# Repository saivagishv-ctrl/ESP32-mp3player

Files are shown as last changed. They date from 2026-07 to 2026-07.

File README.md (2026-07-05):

This is my first ever pcb project, I used AI to ask questions about the KiCAD ui, and to recommend me a specifec model number when i gave it constraints for what i wanted in a component, like the charging module for the battery with passthrough and voltage detection
breakdown of cost: jlcpcb manufacturing total:35 dollar (so much shipping cost and no way to cancel it, not even with other companies)
parts cost on jlcpcb: 25ish dollars without shipping

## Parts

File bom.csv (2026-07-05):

Designator | Footprint | Quantity | Value | LCSC Part #
BT1 | JST_PH_S2B-PH-K_1x02_P2.00mm_Horizontal | 1 | batt
C1, C13, C15, C2, C5 | 0805 | 5 | 10 uF
C10, C11 | 0805 | 2 | 2.2 nF
C12, C14 | 0805 | 2 | 0.1 uF
C16, C17, C6 | 0805 | 3 | 100 nF
C3 | 0805 | 1 | 1uF
C4 | 0805 | 1 | 47 uf
C7, C8 | 0805 | 2 | 2.2 uF
C9 | 0805 | 1 | 1 uF
J1 | USB_C_Receptacle_GCT_USB4105-xx-A_16P_TopMnt_Horizontal | 1 | USB_C_Receptacle_USB2.0_16P
J16 | PinHeader_1x14_P2.54mm_Vertical | 1 | PINHD_1x14_Male
J2 | Jack_3.5mm_CUI_SJ1-3533NG_Horizontal | 1 | AudioJack3
J3 | microSD_HC_Molex_104031-0811 | 1 | Micro_SD_Card_Det1
R1 | R_Axial_DIN0207_L6.3mm_D2.5mm_P10.16mm_Horizontal | 1 | 2k
R10, R11, R12, R13, R14, R15, R16, R17, R2, R3, R4, R9 | R_Axial_DIN0207_L6.3mm_D2.5mm_P10.16mm_Horizontal | 12 | 10k
R5, R8 | R_Axial_DIN0207_L6.3mm_D2.5mm_P10.16mm_Horizontal | 2 | 470ohm
R6, R7 | R_Axial_DIN0207_L6.3mm_D2.5mm_P10.16mm_Horizontal | 2 | 5.1k
SW1, SW2 | SW_Push_SPST_NO_Alps_SKRK | 2 | SW_SPST
U1 | QFN-20-1EP_4x4mm_P0.5mm_EP2.5x2.5mm | 1 | MCP73871-2CC
U2 | ESP32-S3-WROOM-1 | 1 | ESP32-S3-WROOM-1
U3 | SOT-223-3_TabPin2 | 1 | LT1963AxST-3.3
U4 | TSSOP-20_4.4x6.5mm_P0.65mm | 1 | PCM5102A

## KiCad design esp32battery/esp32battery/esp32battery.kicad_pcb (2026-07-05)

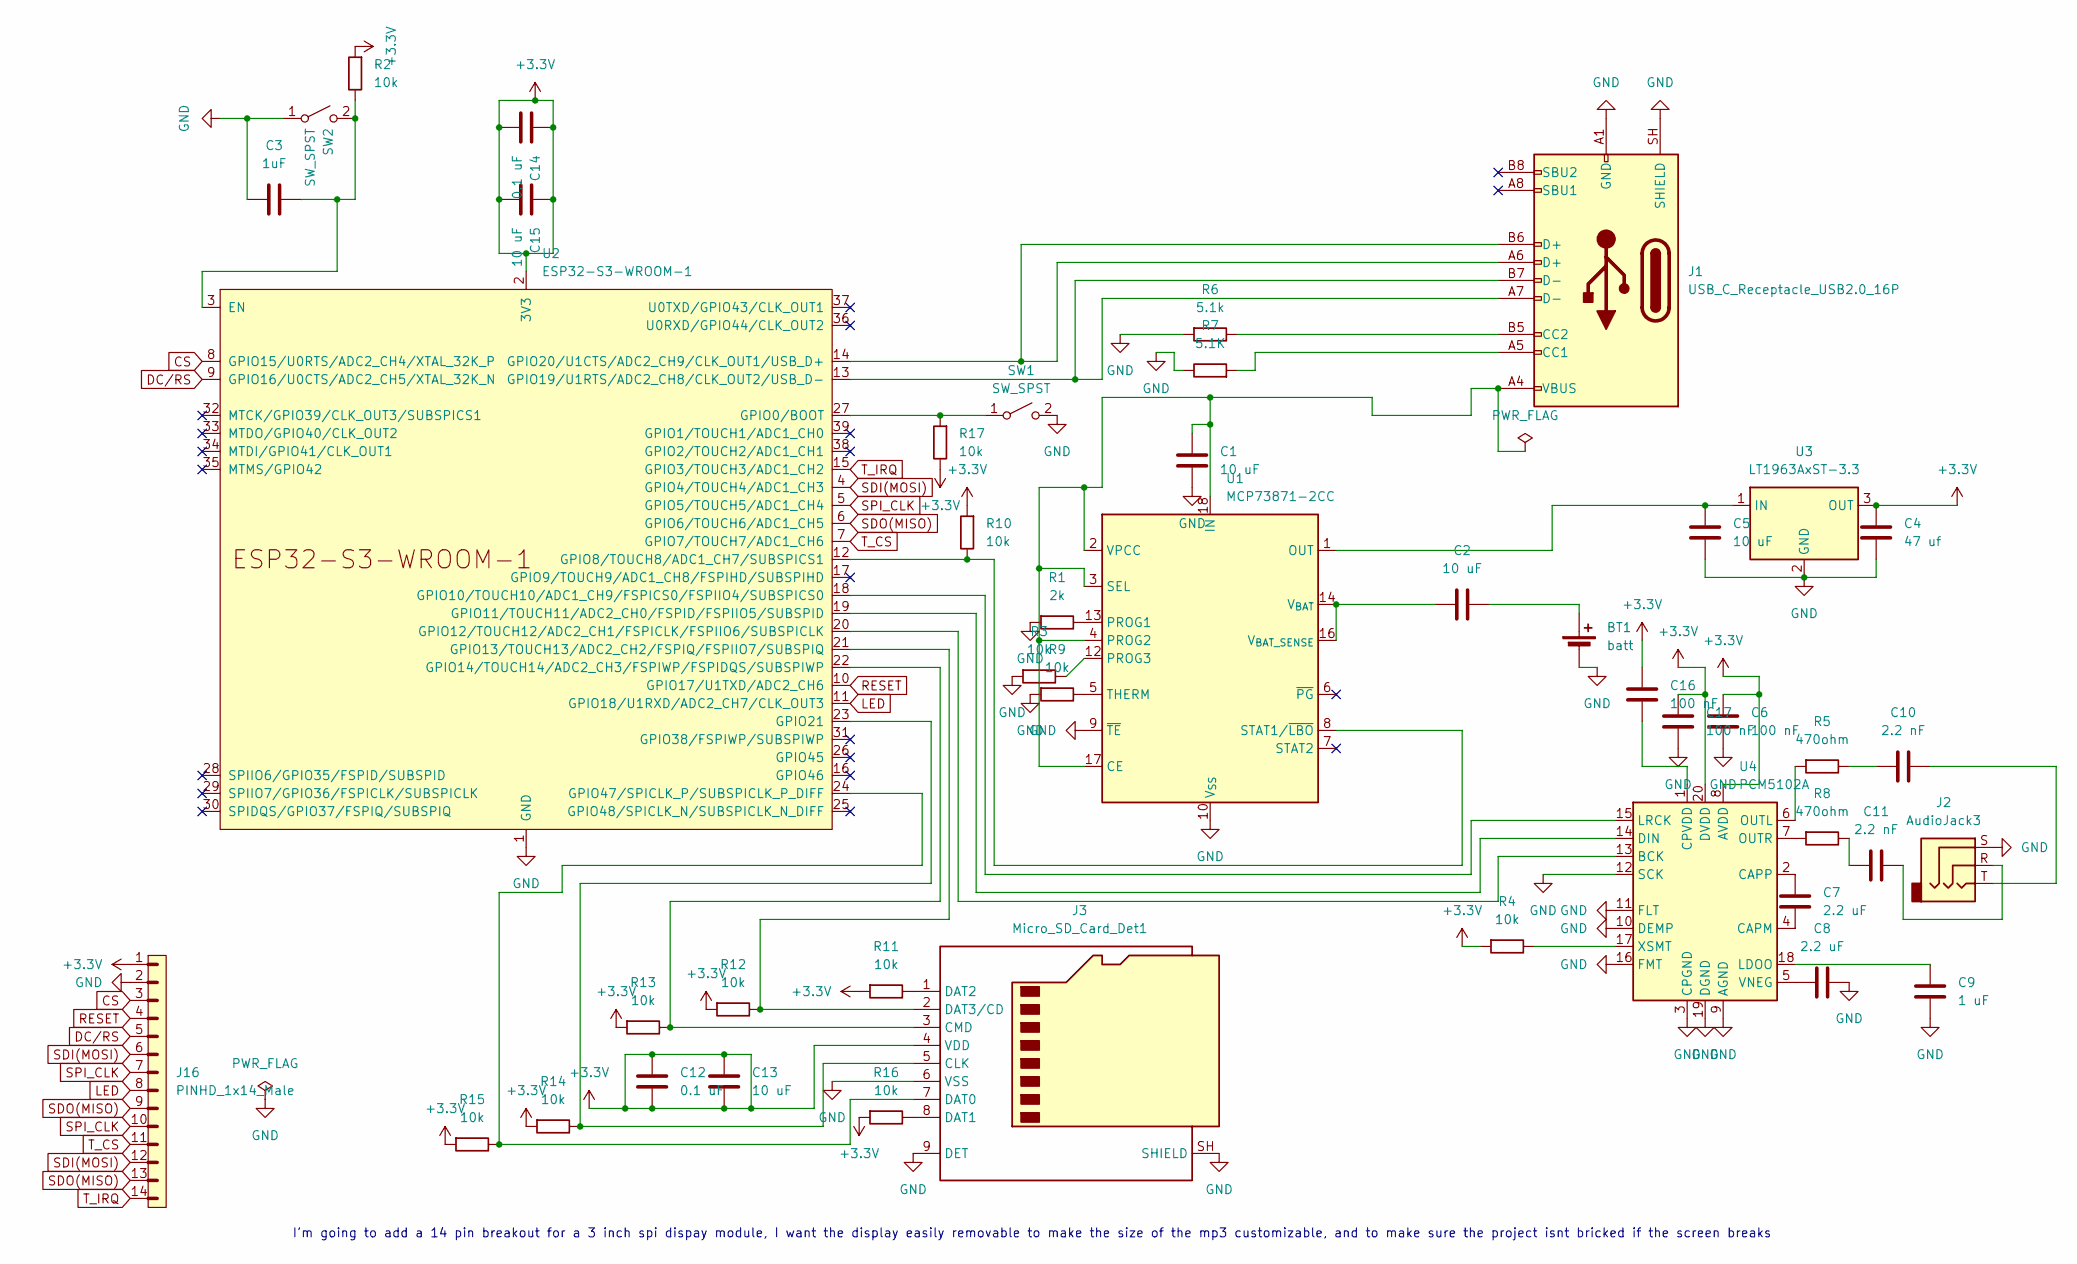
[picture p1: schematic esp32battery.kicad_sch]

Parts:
BT1: batt; JST_PH_S2B-PH-K_1x02_P2.00mm_Horizontal
C1, C2, C5, C13, C15: 10 uF; C_0805_2012Metric_Pad1.18x1.45mm_HandSolder
C3: 1uF; C_0805_2012Metric_Pad1.18x1.45mm_HandSolder
C4: 47 uf; C_0805_2012Metric_Pad1.18x1.45mm_HandSolder
C6, C16, C17: 100 nF; C_0805_2012Metric_Pad1.18x1.45mm_HandSolder
C7, C8: 2.2 uF; C_0805_2012Metric_Pad1.18x1.45mm_HandSolder
C9: 1 uF; C_0805_2012Metric_Pad1.18x1.45mm_HandSolder
C10, C11: 2.2 nF; C_0805_2012Metric_Pad1.18x1.45mm_HandSolder
C12, C14: 0.1 uF; C_0805_2012Metric_Pad1.18x1.45mm_HandSolder
J1: USB_C_Receptacle_USB2.0_16P; USB_C_Receptacle_GCT_USB4105-xx-A_16P_TopMnt_Horizontal
J2: AudioJack3; Jack_3.5mm_CUI_SJ1-3533NG_Horizontal
J3: Micro_SD_Card_Det1; microSD_HC_Molex_104031-0811
J16: PINHD_1x14_Male; PinHeader_1x14_P2.54mm_Vertical
R1: 2k; R_Axial_DIN0207_L6.3mm_D2.5mm_P10.16mm_Horizontal
R2, R3, R4, R9, R10, R11, R12, R13, R14, R15, R16, R17: 10k; R_Axial_DIN0207_L6.3mm_D2.5mm_P10.16mm_Horizontal
R5, R8: 470ohm; R_Axial_DIN0207_L6.3mm_D2.5mm_P10.16mm_Horizontal
R6: 5.1k; R_Axial_DIN0207_L6.3mm_D2.5mm_P10.16mm_Horizontal
R7: 5.1K; R_Axial_DIN0207_L6.3mm_D2.5mm_P10.16mm_Horizontal
SW1, SW2: SW_SPST; SW_Push_SPST_NO_Alps_SKRK
U1: MCP73871-2CC; QFN-20-1EP_4x4mm_P0.5mm_EP2.5x2.5mm
U2: ESP32-S3-WROOM-1
U3: LT1963AxST-3.3; SOT-223-3_TabPin2
U4: PCM5102A; TSSOP-20_4.4x6.5mm_P0.65mm

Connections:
+3.3V: C4.1, C6.1, C12.1, C12.2, C13.1, C13.2, C14.1, C14.2, C15.1, C15.2, C16.1, C17.1, J3.4 (VDD), J16.1, R2.1, R4.1, R10.1, R11.1, R12.1, R13.1, R14.1, R15.1, R16.1, R17.2, U2.2 (3V3), U3.3 (OUT), U4.8 (AVDD), U4.20 (DVDD)
CS: J16.3, U2.8 (GPIO15/U0RTS/ADC2_CH4/XTAL_32K_P)
DC/RS: J16.5, U2.9 (GPIO16/U0CTS/ADC2_CH5/XTAL_32K_N)
GND: BT1.2 (-), C1.2, C3.2, C4.2, C5.2, C6.2, C8.1, C9.2, C17.2, J1.A1 (GND), J1.A12 (GND), J1.B1 (GND), J1.B12 (GND), J1.SH (SHIELD), J2.S, J3.6 (VSS), J3.9 (DET), J3.SH (SHIELD), J16.2, R1.1, R3.1, R6.1, R7.2, R9.1, SW1.2 (B), SW2.1 (A), U1.9 (~TE), U1.10 (V_{SS}), U1.11 (V_{SS}), U1.21 (V_{SS}), U2.1 (GND), U2.40 (GND), U2.41 (GND), U3.2 (GND), U4.3 (CPGND), U4.9 (AGND), U4.10 (DEMP), U4.11 (FLT), U4.12 (SCK), U4.16 (FMT), U4.19 (DGND)
LED: J16.8, U2.11 (GPIO18/U1RXD/ADC2_CH7/CLK_OUT3)
unnamed: BT1.1 (+), C2.1
unnamed: C10.1, J2.T
unnamed: C10.2, R5.2
unnamed: C11.1, R8.2
unnamed: C11.2, J2.R
unnamed: J1.A5 (CC1), R7.1
unnamed: J1.B5 (CC2), R6.2
unnamed: J3.5 (CLK), R14.2, U2.23 (GPIO21)
unnamed: J3.3 (CMD), R13.2, U2.22 (GPIO14/TOUCH14/ADC2_CH3/FSPIWP/FSPIDQS/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)
unnamed: J3.7 (DAT0), R15.2, U2.24 (GPIO47/SPICLK_P/SUBSPICLK_P_DIFF)
unnamed: J3.8 (DAT1), R16.2
unnamed: J3.1 (DAT2), R11.2
unnamed: J3.2 (DAT3/CD), R12.2, U2.21 (GPIO13/TOUCH13/ADC2_CH2/FSPIQ/FSPIIO7/S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)
unnamed: R17.1, SW1.1 (A), U2.27 (GPIO0/BOOT)
unnamed: C3.1, R2.2, SW2.2 (B), U2.3 (EN)
unnamed: C1.1, J1.A4 (VBUS), J1.A9 (VBUS), J1.B4 (VBUS), J1.B9 (VBUS), U1.2 (VPCC), U1.3 (SEL), U1.4 (PROG2), U1.17 (CE), U1.18 (IN), U1.19 (IN)
unnamed: R1.2, U1.13 (PROG1)
unnamed: R3.2, U1.12 (PROG3)
unnamed: R10.2, U1.8 (STAT1/~LBO), U2.12 (GPIO8/TOUCH8/ADC1_CH7/SUBSPICS1)
unnamed: R9.2, U1.5 (THERM)
unnamed: C2.2, U1.14 (V_{BAT}), U1.15 (V_{BAT}), U1.16 (V_{BAT_SENSE})
unnamed: U2.18 (GPIO10/TOUCH10/ADC1_CH9/FSPICS0/FSPIIO4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), U4.15 (LRCK)
unnamed: U2.19 (GPIO11/TOUCH11/ADC2_CH0/FSPID/FSPIIO5/S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), U4.14 (DIN)
unnamed: U2.20 (GPIO12/TOUCH12/ADC2_CH1/FSPICLK/FSPIIO6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), U4.13 (BCK)
unnamed: J1.A7 (D-), J1.B7 (D-), U2.13 (GPIO19/U1RTS/ADC2_CH8/CLK_OUT2/USB_D-)
unnamed: J1.A6 (D+), J1.B6 (D+), U2.14 (GPIO20/U1CTS/ADC2_CH9/CLK_OUT1/USB_D+)
unnamed: C5.1, U1.1 (OUT), U1.20 (OUT), U3.1 (IN)
unnamed: C7.2, U4.4 (CAPM)
unnamed: C7.1, U4.2 (CAPP)
unnamed: C16.2, U4.1 (CPVDD)
unnamed: C9.1, U4.18 (LDOO)
unnamed: R5.1, U4.6 (OUTL)
unnamed: R8.1, U4.7 (OUTR)
unnamed: C8.2, U4.5 (VNEG)
unnamed: R4.2, U4.17 (XSMT)
RESET: J16.4, U2.10 (GPIO17/U1TXD/ADC2_CH6)
SDI(MOSI): J16.6, J16.12, U2.4 (GPIO4/TOUCH4/ADC1_CH3)
SDO(MISO): J16.9, J16.13, U2.6 (GPIO6/TOUCH6/ADC1_CH5)
SPI_CLK: J16.7, J16.10, U2.5 (GPIO5/TOUCH5/ADC1_CH4)
T_CS: J16.11, U2.7 (GPIO7/TOUCH7/ADC1_CH6)
T_IRQ: J16.14, U2.15 (GPIO3/TOUCH3/ADC1_CH2)

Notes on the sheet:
I'm going to add a 14 pin breakout for a 3 inch spi dispay module, I want the display easily removable to make the size of the mp3 customizable, and to make sure the project isnt bricked if the screen breaks

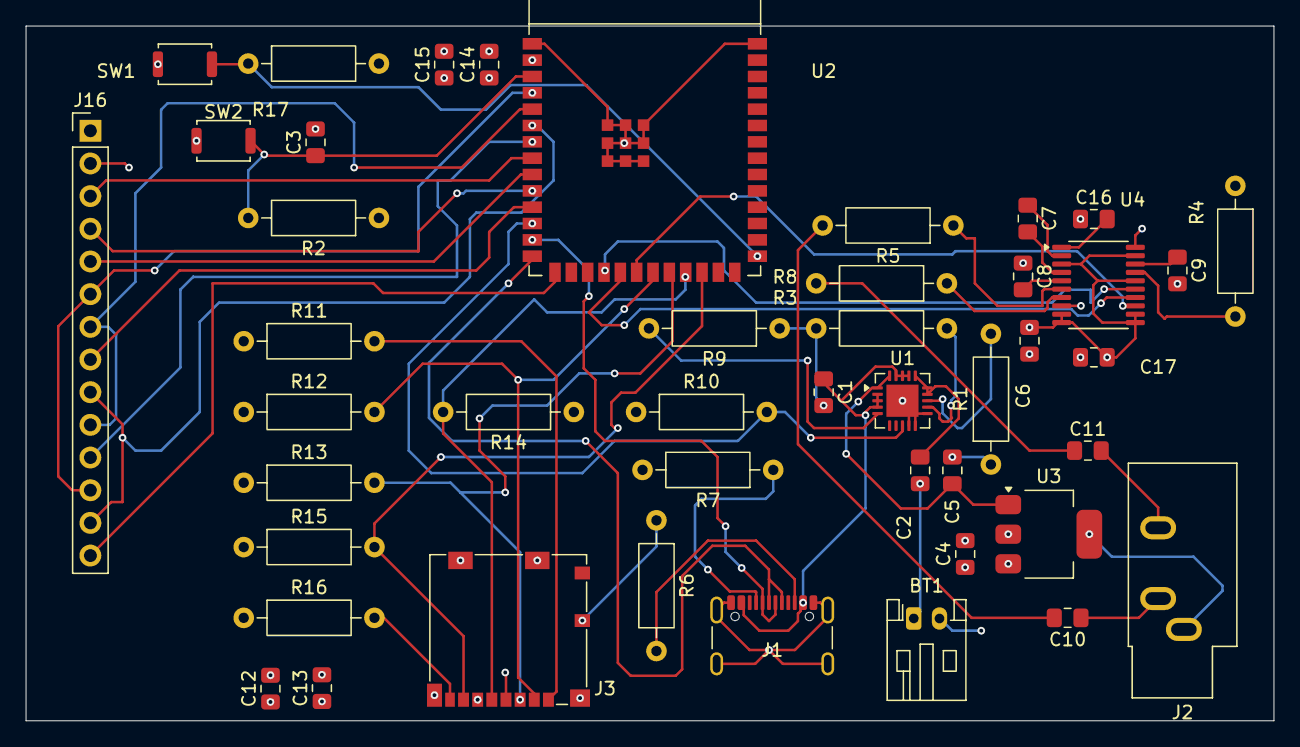
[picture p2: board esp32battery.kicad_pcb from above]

Board: 4 copper layers, 97.0 x 54.0 mm, 45 parts (0 on the bottom side), 46 nets.
